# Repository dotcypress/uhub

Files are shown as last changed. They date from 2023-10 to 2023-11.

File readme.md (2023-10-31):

## μHub

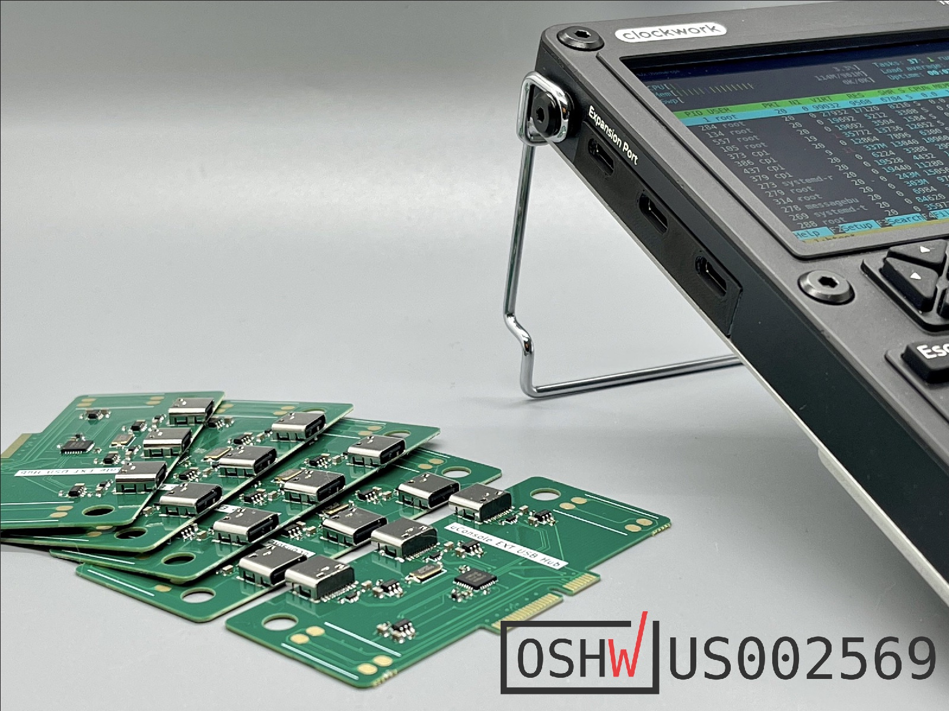
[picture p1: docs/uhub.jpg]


### What is it?

μHub is USB Hub Expansion Card designed for [Clockwork uConsole](https://www.clockworkpi.com/uconsole).

### Features

* Internal Speakers Support
* 3 Type-C (USB 2.0) ports with power switch and overcurrent protection
* 1 Internal FFC (USB 2.0) port with power switch and overcurrent protection



## Resources

- [Cover Bracket 3D model](docs/cover.stl)
- [Schematics](docs/uhub.pdf)
- [PCB Viewer](https://kicanvas.org/?github=https%3A%2F%2Fgithub.com%2Fdotcypress%2Fuhub%2Fblob%2Fmain%2Fuhub.kicad_pcb)
- [Interactive BOM](https://htmlpreview.github.io/?https://github.com/dotcypress/uhub/blob/main/docs/ibom.html)

## License

Licensed under either of

- Apache License, Version 2.0 ([LICENSE-APACHE](LICENSE-APACHE) or
  http://www.apache.org/licenses/LICENSE-2.0)
- MIT license ([LICENSE-MIT](LICENSE-MIT) or http://opensource.org/licenses/MIT)

at your option.

### Contribution

Unless you explicitly state otherwise, any contribution intentionally submitted
for inclusion in the work by you, as defined in the Apache-2.0 license, shall be
dual licensed as above, without any additional terms or conditions.

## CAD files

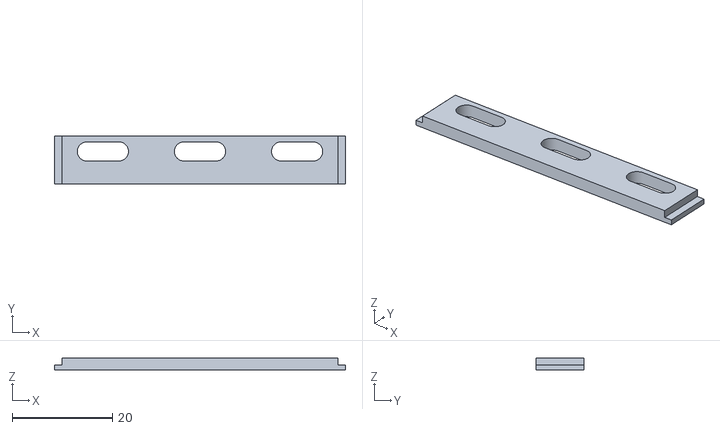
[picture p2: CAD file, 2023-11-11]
docs/cover.stl
58.0 x 9.50 x 2.40

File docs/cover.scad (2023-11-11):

$fn=128;
epsilon=0.01;

module usb() {
  hull() {
    translate([3.2, 0, 0])
      cylinder(r=1.9, h=20, center=true);
    translate([-3.2, 0, 0])
      cylinder(r=1.9, h=20, center=true);
  }
}

module cover() {
  difference() {
    union() {
      cube(size=[58, 9.5, 1], center=true);
      translate([0, 0, 1])
        cube(size=[55, 9.5, 1.8], center=true);
    }
    translate([-19.35, 1.7, 0]) usb();
    translate([0, 1.7, 0]) usb();
    translate([19.35, 1.7, 0]) usb();
  }
}

module print() {
  translate([10, 4, 0.5]) 
    cube(size=[1, 88, 1], center=true);
  translate([-10, 4, 0.5]) 
    cube(size=[1, 88, 1], center=true);
  for (i=[-3:4]) {
    translate([0, i*12, 0.6]) cover();
  }
}

// print();
cover();

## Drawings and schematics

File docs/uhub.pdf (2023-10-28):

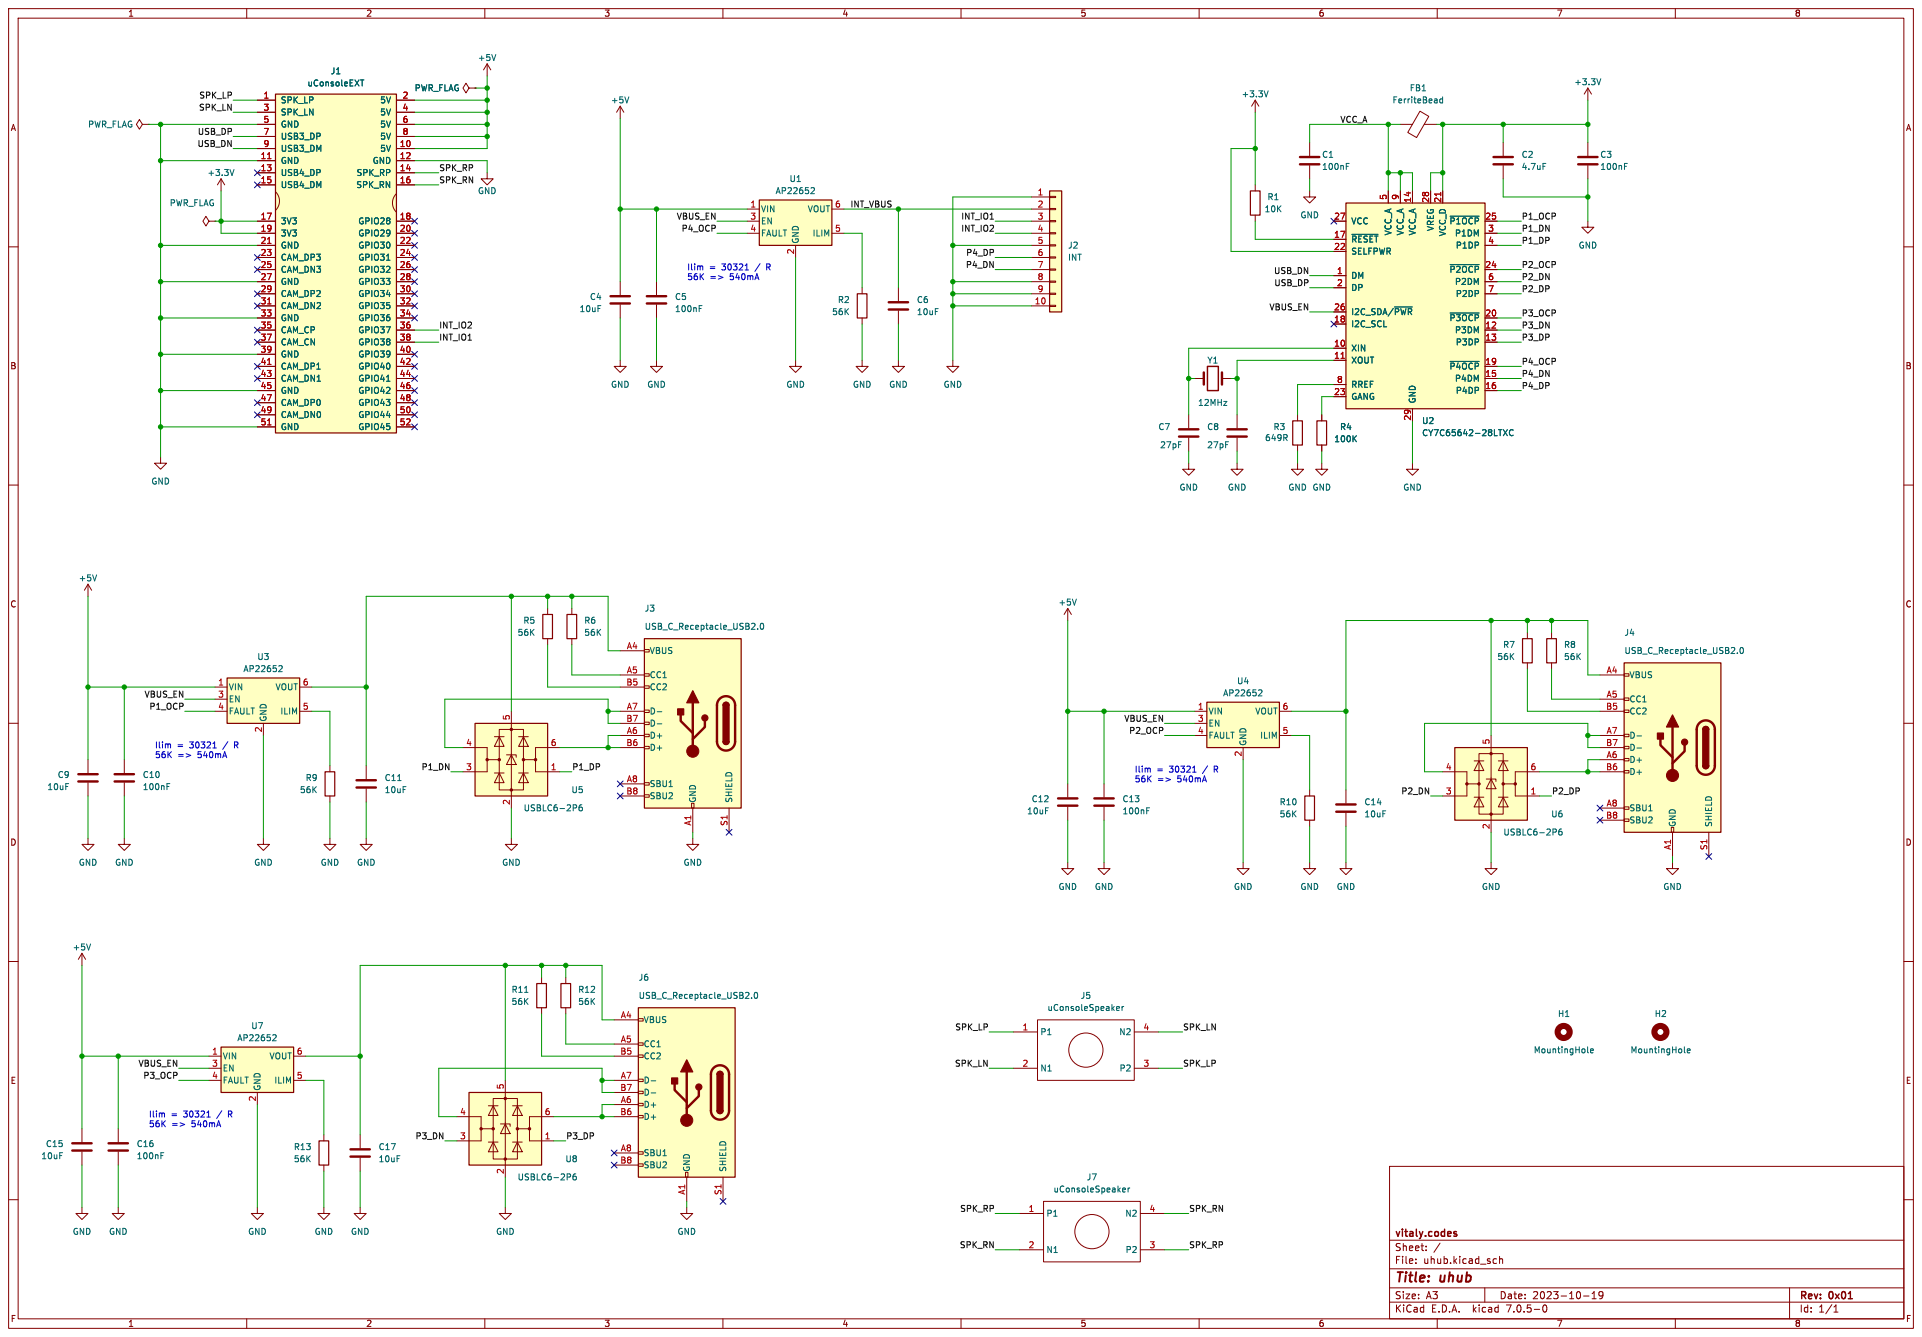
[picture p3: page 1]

File: uhub.kicad_sch Sheet: / vitaly.codes

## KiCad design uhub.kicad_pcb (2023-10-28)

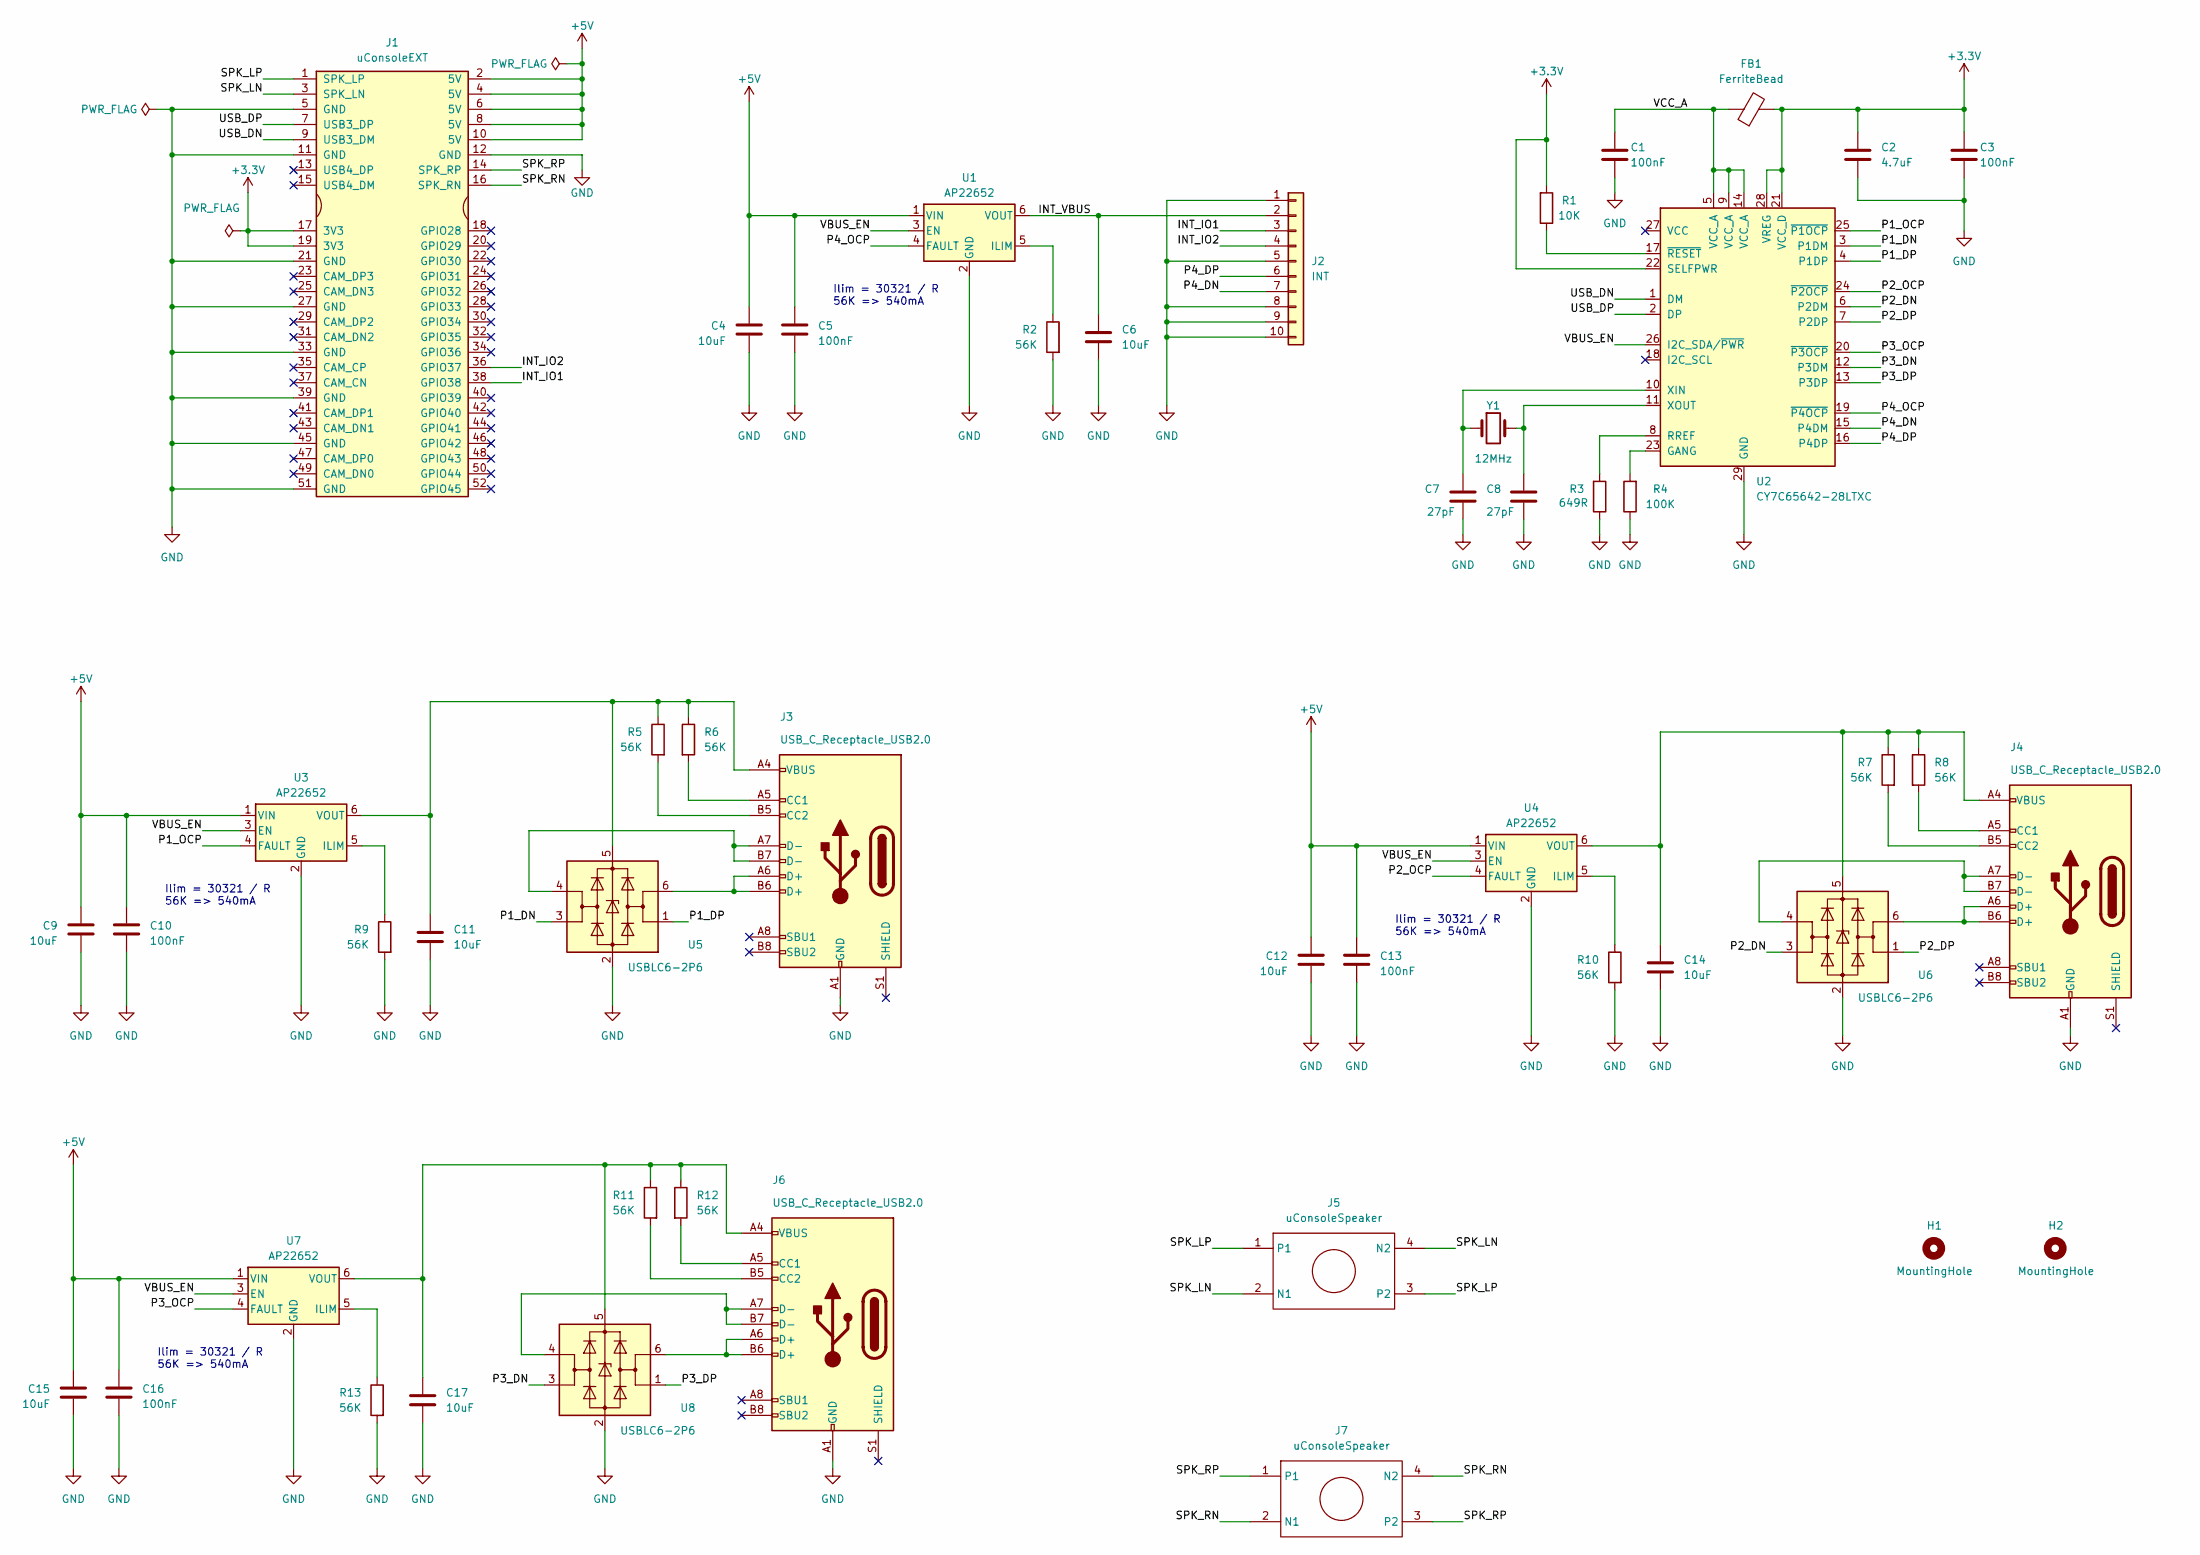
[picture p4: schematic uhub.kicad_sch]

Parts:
C1, C3, C5, C10, C13, C16: 100nF; C_0402_1005Metric
C2: 4.7uF; C_0402_1005Metric
C4, C6, C9, C11, C12, C14, C15, C17: 10uF; C_0603_1608Metric
C7, C8: 27pF; C_0402_1005Metric
FB1: FerriteBead; R_0603_1608Metric
H1, H2: MountingHole; MountingHole_5.3mm_M5
J1: uConsoleEXT; ext
J2: INT; Hirose_FH12-10S-0.5SH_1x10-1MP_P0.50mm_Horizontal
J3, J4, J6: USB_C_Receptacle_USB2.0; USB_C_Receptacle_HRO_TYPE-C-31-M-12
J5, J7: uConsoleSpeaker; speaker
R1: 10K; R_0402_1005Metric
R2, R5, R6, R7, R8, R9, R10, R11, R12, R13: 56K; R_0402_1005Metric
R3: 649R; R_0402_1005Metric
R4: 100K; R_0402_1005Metric
U1, U3, U4, U7: AP22652; SOT-23-6
U2: CY7C65642-28LTXC; QFN-28-1EP_5x5mm_P0.5mm_EP3.35x3.35mm
U5, U6, U8: USBLC6-2P6; SOT-666
Y1: 12MHz; Crystal_SMD_5032-2Pin_5.0x3.2mm

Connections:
+3.3V: C2.1, C3.1, FB1.2, J1.17 (3V3), J1.19 (3V3), R1.2, U2.21 (VCC_D), U2.22 (SELFPWR), U2.28 (VREG)
+5V: C4.2, C5.2, C9.2, C10.2, C12.2, C13.2, C15.2, C16.2, J1.2 (5V), J1.4 (5V), J1.6 (5V), J1.8 (5V), J1.10 (5V), U1.1 (VIN), U3.1 (VIN), U4.1 (VIN), U7.1 (VIN)
/INT_IO1: J1.38 (GPIO38), J2.3
/INT_IO2: J1.36 (GPIO37), J2.4
/INT_VBUS: C6.1, J2.2, U1.6 (VOUT)
/P1_DN: U2.3 (P1DM), U5.3 (I/O2)
/P1_DP: U2.4 (P1DP), U5.1 (I/O1)
/P1_OCP: U2.25 (~P1OCP), U3.4 (FAULT)
/P2_DN: U2.6 (P2DM), U6.3 (I/O2)
/P2_DP: U2.7 (P2DP), U6.1 (I/O1)
/P2_OCP: U2.24 (~P2OCP), U4.4 (FAULT)
/P3_DN: U2.12 (P3DM), U8.3 (I/O2)
/P3_DP: U2.13 (P3DP), U8.1 (I/O1)
/P3_OCP: U2.20 (~P3OCP), U7.4 (FAULT)
/P4_DN: J2.7, U2.15 (P4DM)
/P4_DP: J2.6, U2.16 (P4DP)
/P4_OCP: U1.4 (FAULT), U2.19 (~P4OCP)
/SPK_LN: J1.3 (SPK_LN), J5.2 (N1), J5.4 (N2)
/SPK_LP: J1.1 (SPK_LP), J5.1, J5.3 (P2)
/SPK_RN: J1.16 (SPK_RN), J7.2 (N1), J7.4 (N2)
/SPK_RP: J1.14 (SPK_RP), J7.1, J7.3 (P2)
/USB_DN: J1.9 (USB3_DM), U2.1 (DM)
/USB_DP: J1.7 (USB3_DP), U2.2 (DP)
/VBUS_EN: U1.3 (EN), U2.26 (I2C_SDA/~PWR), U3.3 (EN), U4.3 (EN), U7.3 (EN)
/VCC_A: C1.1, FB1.1, U2.5 (VCC_A), U2.9 (VCC_A), U2.14 (VCC_A)
GND: C1.2, C2.2, C3.2, C4.1, C5.1, C6.2, C7.2, C8.2, C9.1, C10.1, C11.2, C12.1, C13.1, C14.2, C15.1, C16.1, C17.2, J1.5 (GND), J1.11 (GND), J1.12 (GND), J1.21 (GND), J1.27 (GND), J1.33 (GND), J1.39 (GND), J1.45 (GND), J1.51 (GND), J2.1, J2.5, J2.8, J2.9, J2.10, J3.A1 (GND), J3.A12 (GND), J3.B1 (GND), J3.B12 (GND), J4.A1 (GND), J4.A12 (GND), J4.B1 (GND), J4.B12 (GND), J6.A1 (GND), J6.A12 (GND), J6.B1 (GND), J6.B12 (GND), R2.2, R3.1, R4.1, R9.2, R10.2, R13.2, U1.2 (GND), U2.29 (GND), U3.2 (GND), U4.2 (GND), U5.2 (GND), U6.2 (GND), U7.2 (GND), U8.2 (GND)
unnamed: J3.A5 (CC1), R6.2
unnamed: J3.B5 (CC2), R5.2
unnamed: J3.A6 (D+), J3.B6 (D+), U5.6 (I/O1)
unnamed: J3.A7 (D-), J3.B7 (D-), U5.4 (I/O2)
unnamed: J4.A5 (CC1), R8.2
unnamed: J4.B5 (CC2), R7.2
unnamed: J4.A6 (D+), J4.B6 (D+), U6.6 (I/O1)
unnamed: J4.A7 (D-), J4.B7 (D-), U6.4 (I/O2)
unnamed: J6.A5 (CC1), R12.2
unnamed: J6.B5 (CC2), R11.2
unnamed: J6.A6 (D+), J6.B6 (D+), U8.6 (I/O1)
unnamed: J6.A7 (D-), J6.B7 (D-), U8.4 (I/O2)
unnamed: R2.1, U1.5 (ILIM)
unnamed: R4.2, U2.23 (GANG)
unnamed: R3.2, U2.8 (RREF)
unnamed: C7.1, U2.10 (XIN), Y1.1
unnamed: C8.1, U2.11 (XOUT), Y1.2
unnamed: R1.1, U2.17 (~RESET)
unnamed: R9.1, U3.5 (ILIM)
unnamed: C11.1, J3.A4 (VBUS), J3.A9 (VBUS), J3.B4 (VBUS), J3.B9 (VBUS), R5.1, R6.1, U3.6 (VOUT), U5.5 (VBUS)
unnamed: R10.1, U4.5 (ILIM)
unnamed: C14.1, J4.A4 (VBUS), J4.A9 (VBUS), J4.B4 (VBUS), J4.B9 (VBUS), R7.1, R8.1, U4.6 (VOUT), U6.5 (VBUS)
unnamed: R13.1, U7.5 (ILIM)
unnamed: C17.1, J6.A4 (VBUS), J6.A9 (VBUS), J6.B4 (VBUS), J6.B9 (VBUS), R11.1, R12.1, U7.6 (VOUT), U8.5 (VBUS)

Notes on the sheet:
Ilim = 30321 / R 56K => 540mA

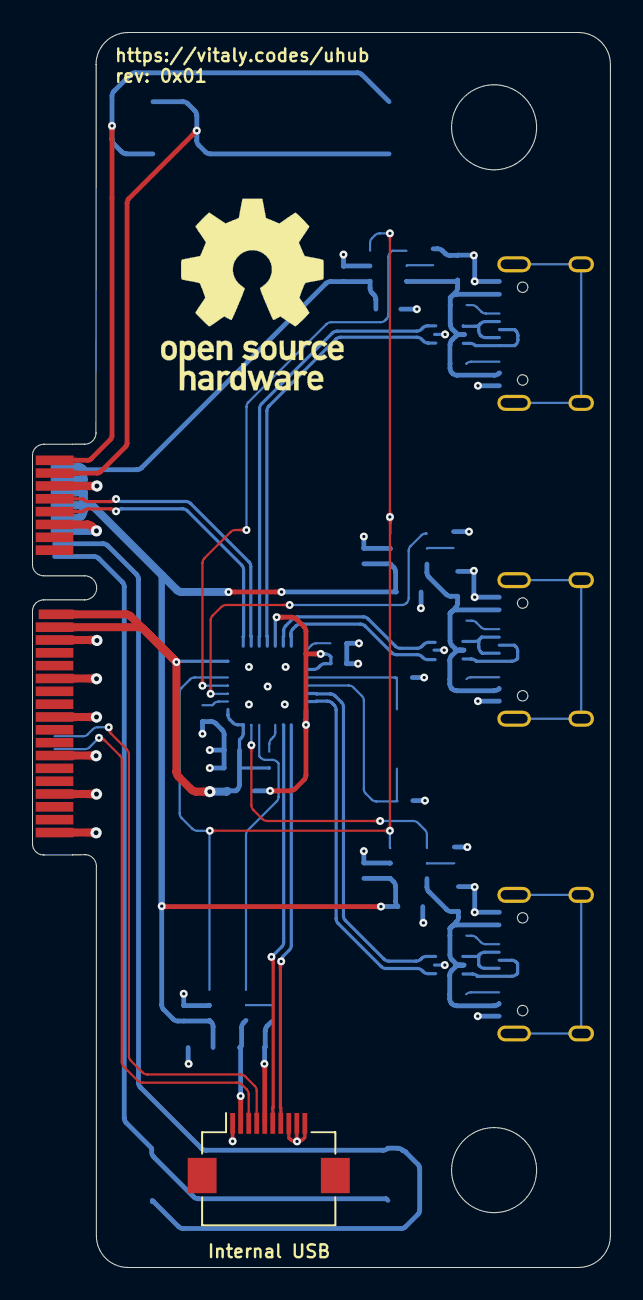
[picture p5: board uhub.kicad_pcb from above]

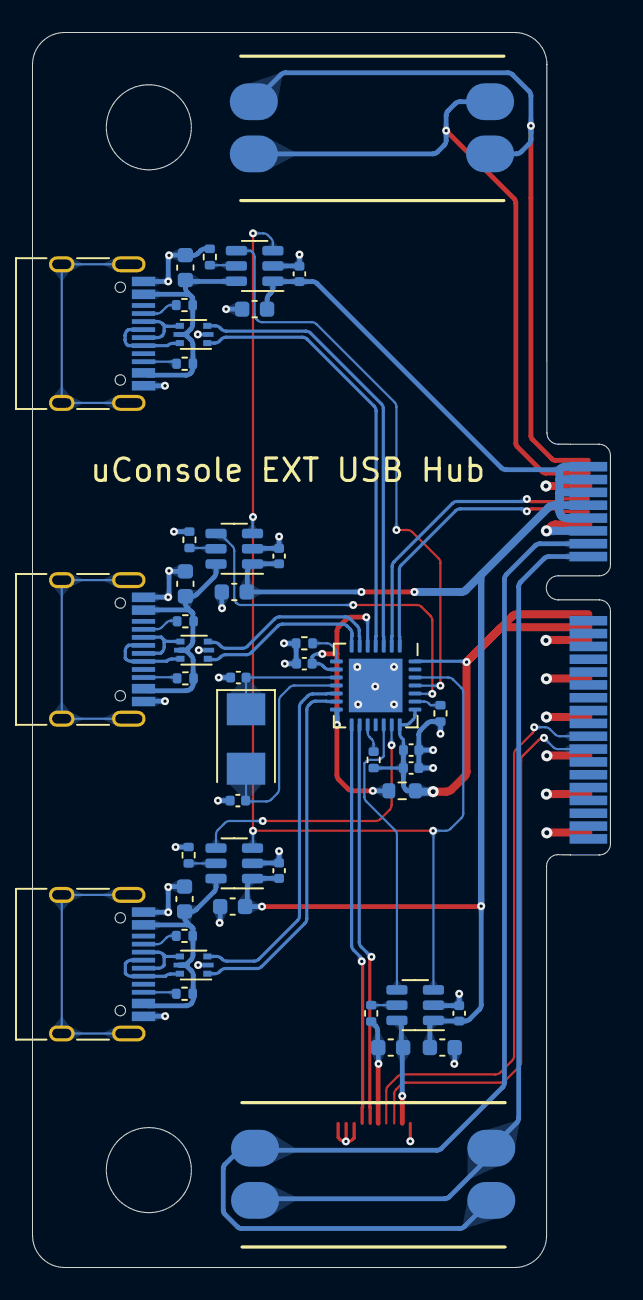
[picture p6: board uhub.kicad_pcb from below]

Board: 4 copper layers, 36.0 x 77.0 mm, 49 parts (45 on the bottom side), 50 nets.

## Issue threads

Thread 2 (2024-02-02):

Q: please explicitelyt define "Internal Speakers Support" here or in upico (lowpri,doconly)

jakobi, 2024-02-02:
This affects both upico and uhub. I skimmed both forum threads on clock work pi, upico+uhub pcb images and the schematics pdfs in both your repos.

My best guess is that I seem to see solder pads suitable for mounting $UNDEFINED_SPEAKER for
$UNDEFINED_SIZE, WATTAGE and IMPEDANCY.

The final two might be hidden somewhere in the uconsole specs or threads, which I've yet to skim.

You you add a small notice in one of the repos and provide a link to a known-suitable example speaker on say mouser? (and crosslinking to that from your other uconsole extension repos?).

Thx,
Peter

PS: First I hoped for a std raspberry pi gpio layout on the upico, but the upico thread disproved that soon enough. but the uconsole and your extensions begin to look _REALLY_ interesting. Keep up the good work!

jakobi, 2024-02-03:
finally found a video showing the main point about those mystery speakers (yt: ikF0pZqpfYw):

the speakers are provided by clockworkpi themselves with the device, but take up space in the ext-module area. If installed, they try to connect to bare contacts on the installed ext-module.

As you can see, reading up on the available modules was part of my subsequent purchase decision, and sweetened the decision commit to waiting for a good number of months :).

I'd still appreciate, if you add a bit info on this in the repos, but otherwise this can be closed now.

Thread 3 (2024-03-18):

No Power

fpiesik, 2024-03-18:
Just received and installed without any problems. However, devices are not recognized because they don't receive power. The readme states that the USB port features power switches. So, how can I control those switches?

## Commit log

2023-10-28 rev 0x01
    [cover.scad, cover.stl, uhub.kicad_pcb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]
2023-10-28 update cover
    [cover.scad, cover.stl]
2023-10-31 update project structure
    [cover.scad, cover.stl]
2023-11-11 cover tuning
    [cover.scad, cover.stl]
